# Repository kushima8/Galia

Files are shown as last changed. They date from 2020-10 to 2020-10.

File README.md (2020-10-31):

# Galia
Split 61-key ergo keyboard with trackball on right-hand side.

## Disclaimer
The layout is based on the [Ergodash](https://github.com/omkbd/ErgoDash) layout with the inner-most keys removed and a modified thumb cluster on the left hand side, and integrated 34mm trackball on the right. The Pro Micro position was also moved inwards to allow for a thinner board. The Ergodash layout was only used as a reference, nothing was copied and the board is a completely new design. Finally, the mechanical design of the [aball](https://github.com/brickbots/aball) was referenced for the design of the trackball mount, but an entirely new design was created.

## Key Features
* Slim design, or as slim as I could get while using standard MX-style Switches. Essentially, the Pro Micro or whatever other microcontroller used mounts under the PCB, flush and facing up with the help of a cutout.
* SMK MX-style switch support, solder only but the holes are mill-max socket compatible.
* OLED support, either using a standard 0.91" SSD1306 OLED or the [Crenshaw](https://github.com/Ariamelon/Crenshaw) 1.3" OLED breakout board.
* Single rotary encoder position replacing the top-most switch of the left thumb cluster.
* 34mm trackball on the right-hand side using the [Ogen](https://github.com/Ariamelon/Ogen) PMW3360 sensor board. Also compatible with [Jack's](https://www.tindie.com/products/jkicklighter/pmw3360-motion-sensor/) version. 
* Useable in both wired and wireless modes.
* Supports either charger on the microcontroller board or an external TP4056-based charger for faster charging. the TP4056 charger is also flush-mounted sitting up and supports the use of 0305 or 7305 mill-max hotswap sockets if desired.
* Case design with plate included with in-built 10° tent. Plate assumes use of the Crenshaw.
* Supports a massive battery due to the large space in the case. I'm personally using 18650 batteries. Go a year without charging!

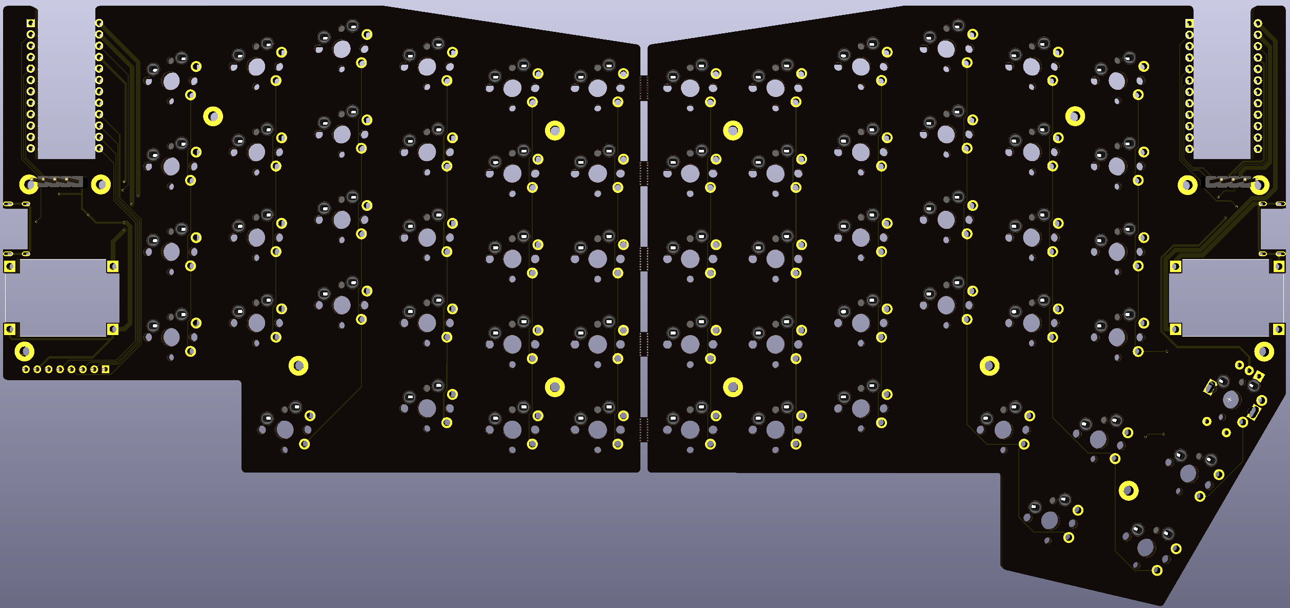
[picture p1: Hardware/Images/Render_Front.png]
Galia Front Render

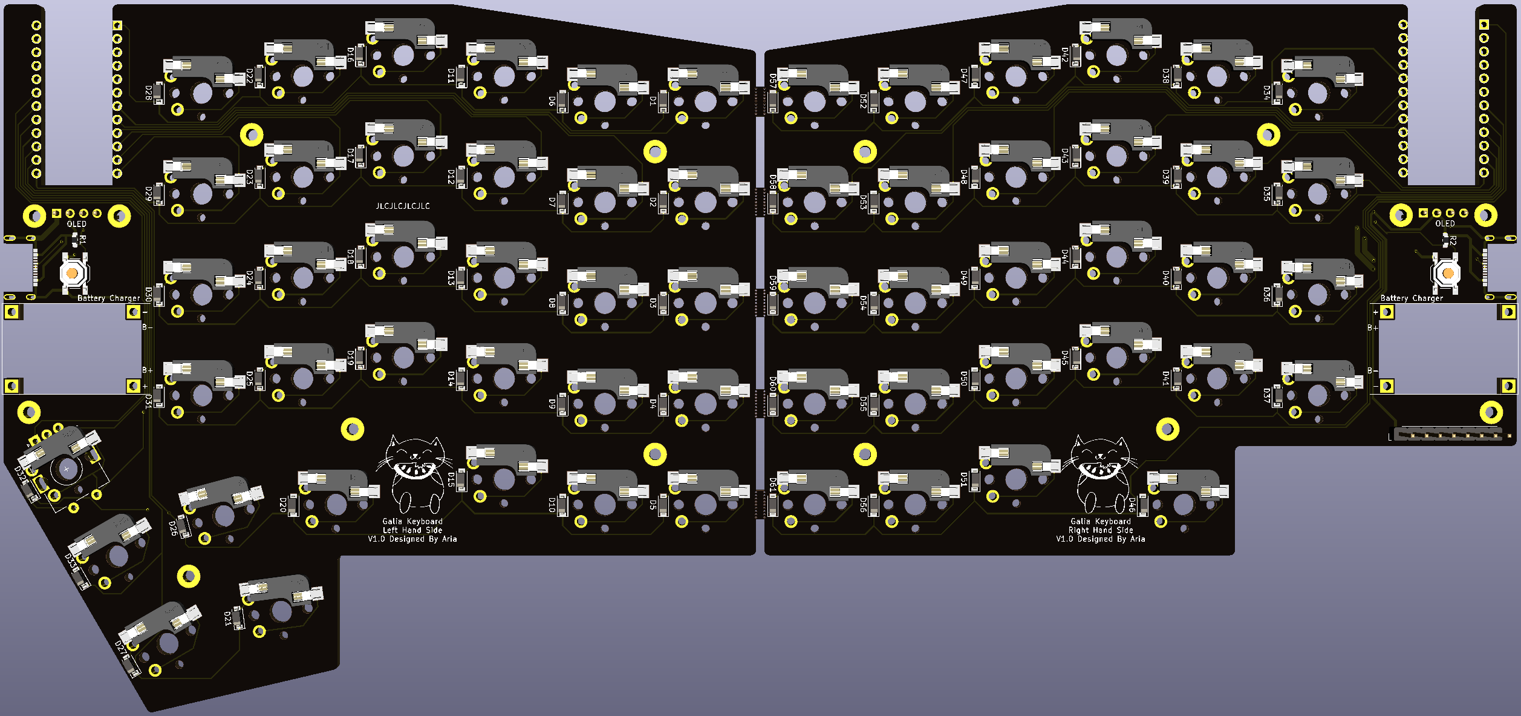
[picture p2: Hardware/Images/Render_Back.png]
Galia Back Render


## Changelog
* 02/10/2020: Initial commit with case.
* 06/10/2020: Added spot for external TP4056 charger board.
* 10/10/2020: Changed reset switch footprint and position, removed useless pull-up resistor.
* 11/10/2020: Now uses much less plastic and the position of the trackball was moved inwards and downwards.

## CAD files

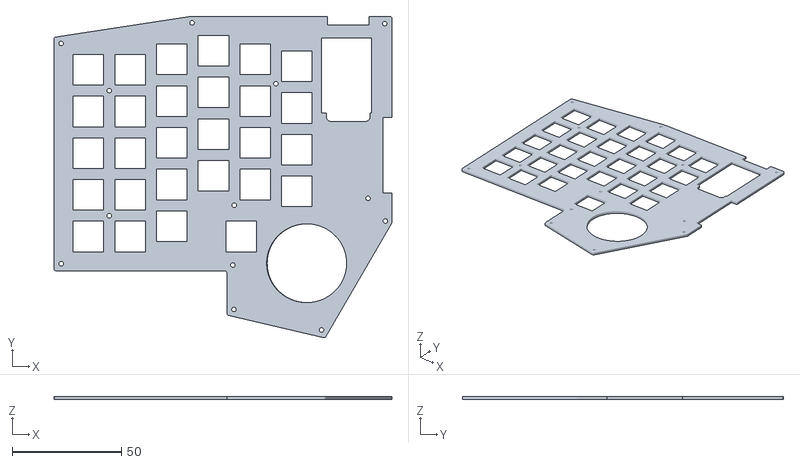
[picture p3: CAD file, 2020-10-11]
Hardware/Case/Plate_R.stl
154.5 x 146.9 x 1.50

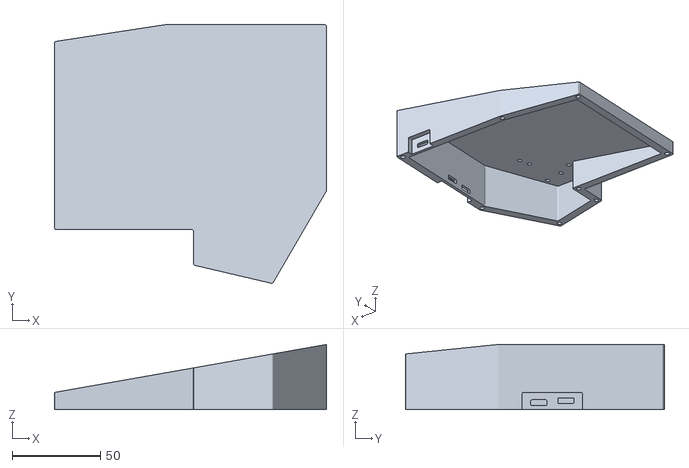
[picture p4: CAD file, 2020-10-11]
Hardware/Case/Case_R.stl
154.5 x 146.9 x 37.0

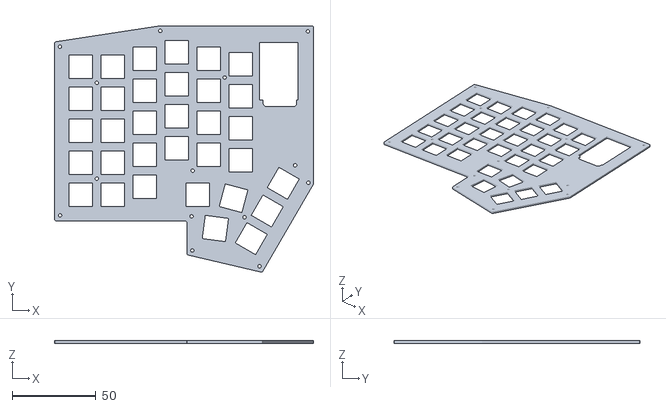
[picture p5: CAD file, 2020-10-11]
Hardware/Case/Plate_L.stl
154.5 x 146.9 x 1.50

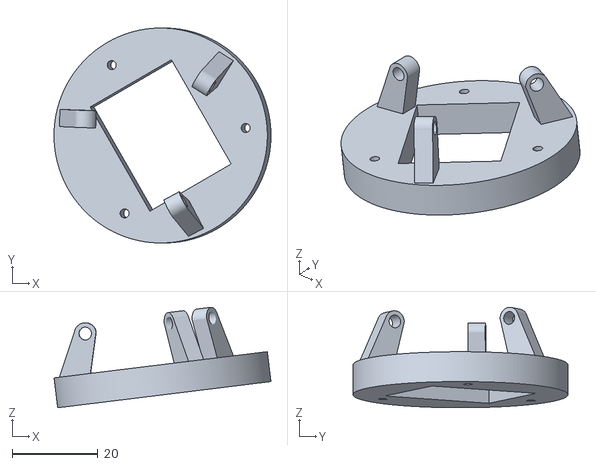
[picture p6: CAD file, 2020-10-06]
Hardware/Case/Trackball_Base.stl
50.5 x 50.0 x 23.4

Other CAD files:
Hardware/Case/Case_L.stl
Hardware/Case/Plate_L.dxf
Hardware/Case/Plate_R.dxf

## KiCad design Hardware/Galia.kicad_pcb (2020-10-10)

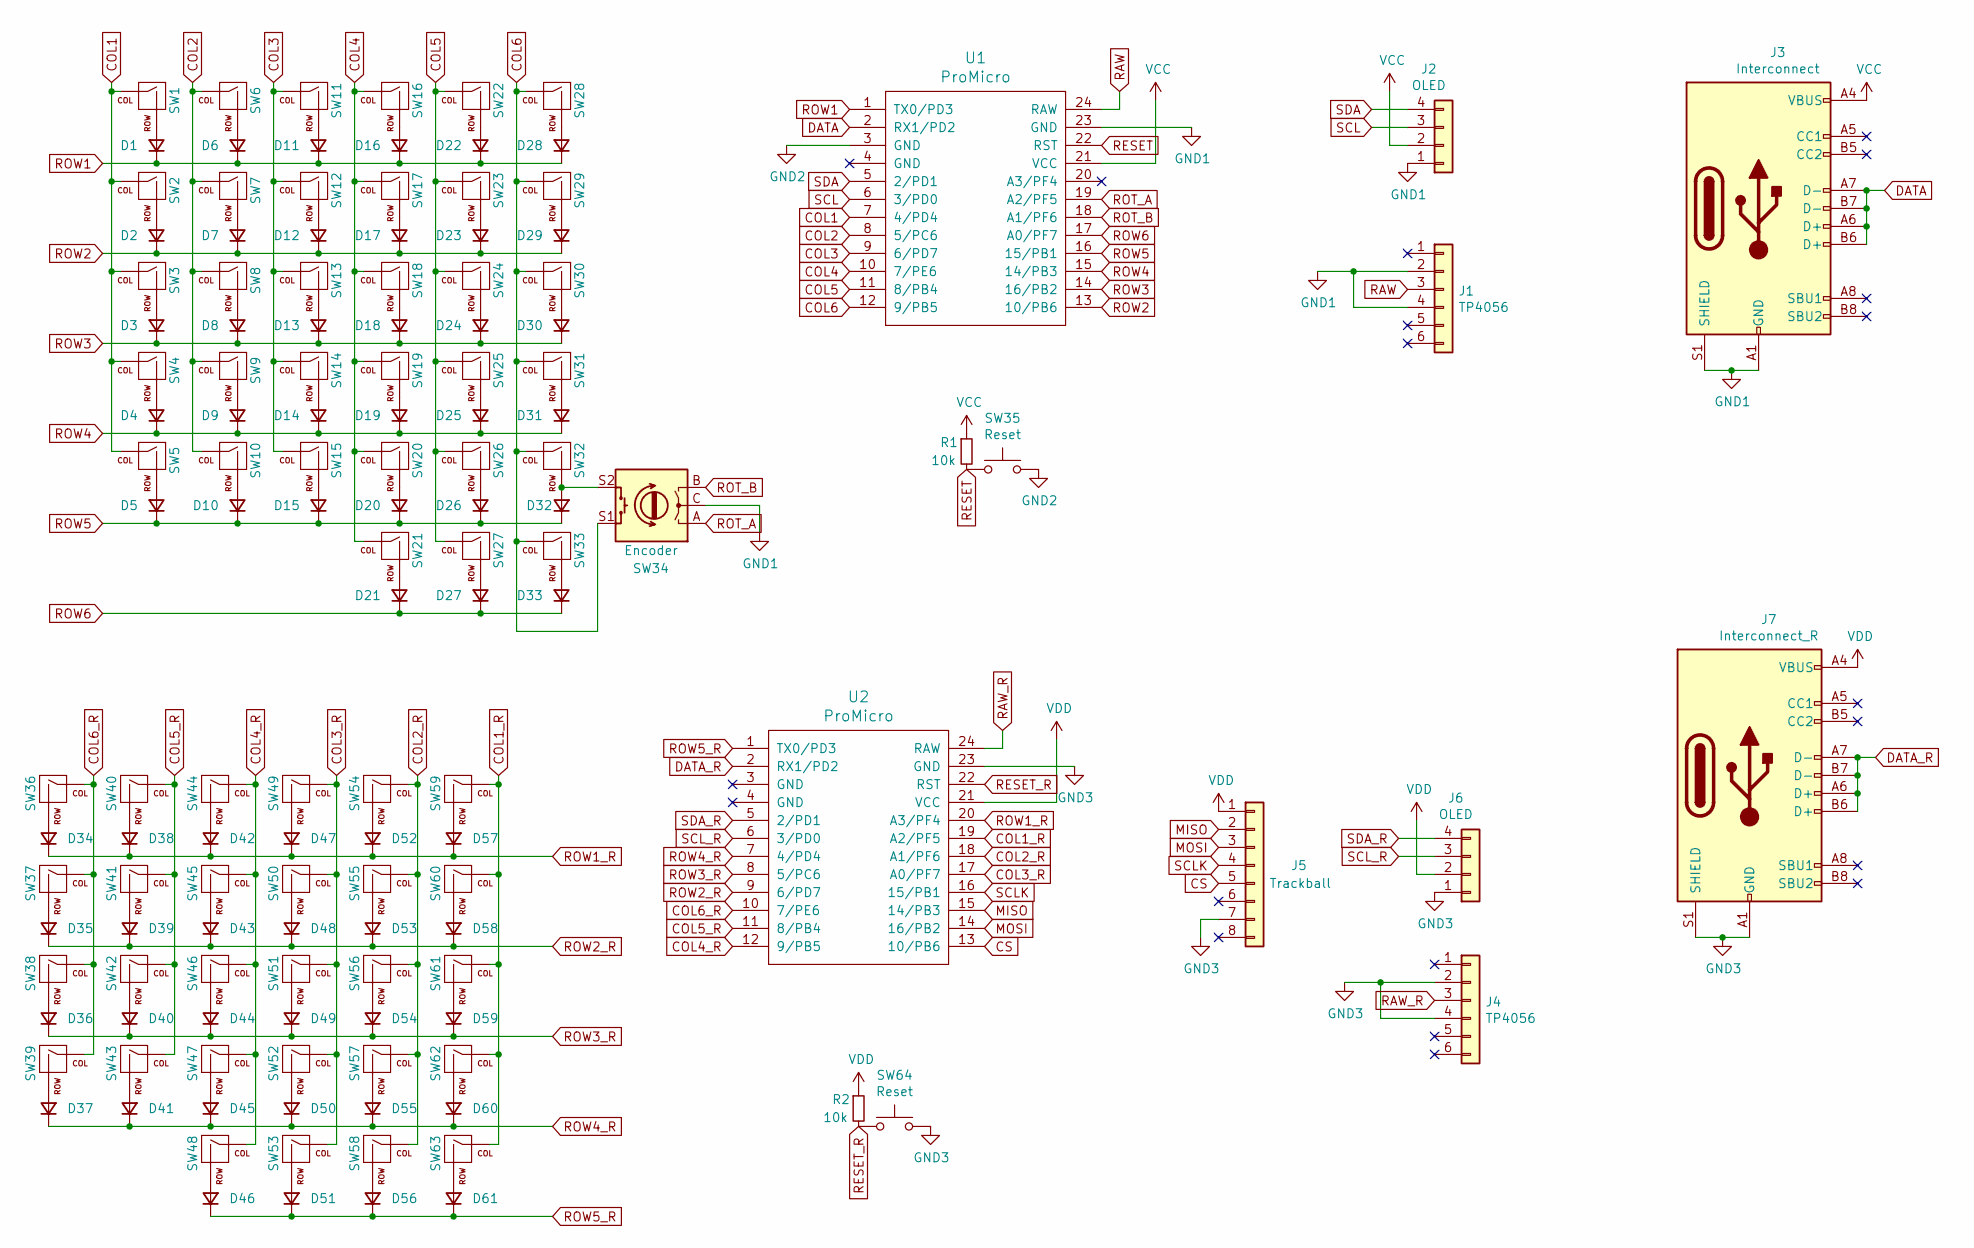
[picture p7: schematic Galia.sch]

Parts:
D1, D2, D3, D4, D5, D6, D7, D8, D9, D10, D11, D12, D13, D14, D15, D16, D17, D18, D19, D20, D21, D22, D23, D24, D25, D26, D27, D28, D29, D30, D31, D32, D33, D34, D35, D36, D37, D38, D39, D40, D41, D42, D43, D44, D45, D46, D47, D48, D49, D50, D51, D52, D53, D54, D55, D56, D57, D58, D59, D60, D61: D; D_SOD-123
J1, J4: TP4056; TP4056-18650
J2, J6: OLED; PinHeader_1x04_P2.54mm_Vertical_No_Silk
J3: Interconnect; USB-C-C168688
J5: Trackball; PinHeader_1x08_P2.54mm_Vertical
J7: Interconnect_R; USB-C-C168688
R1, R2: 10k; R_0603_1608Metric_Pad1.05x0.95mm_HandSolder
SW1, SW2, SW3, SW4, SW5, SW6, SW7, SW8, SW9, SW10, SW11, SW12, SW13, SW14, SW15, SW16, SW17, SW18, SW19, SW20, SW21, SW22, SW23, SW24, SW25, SW26, SW27, SW28, SW29, SW30, SW31, SW32, SW33, SW36, SW37, SW38, SW39, SW40, SW41, SW42, SW43, SW44, SW45, SW46, SW47, SW48, SW49, SW50, SW51, SW52, SW53, SW54, SW55, SW56, SW57, SW58, SW59, SW60, SW61, SW62, SW63: MX; CherryMX_Hotswap_SMK
SW34: Encoder; RotaryEncoder_Alps_EC11E-Switch_Vertical_H20mm
SW35, SW64: Reset; Switch_Tactile_SPST_Angled_MJTP1117
U1, U2: ProMicro; ArduinoProMicro_Blank

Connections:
COL1: SW1.1 (COL), SW2.1 (COL), SW3.1 (COL), SW4.1 (COL), SW5.1 (COL), U1.7 (4/PD4)
COL1_R: SW59.1 (COL), SW60.1 (COL), SW61.1 (COL), SW62.1 (COL), SW63.1 (COL), U2.19 (A2/PF5)
COL2: SW6.1 (COL), SW7.1 (COL), SW8.1 (COL), SW9.1 (COL), SW10.1 (COL), U1.8 (5/PC6)
COL2_R: SW54.1 (COL), SW55.1 (COL), SW56.1 (COL), SW57.1 (COL), SW58.1 (COL), U2.18 (A1/PF6)
COL3: SW11.1 (COL), SW12.1 (COL), SW13.1 (COL), SW14.1 (COL), SW15.1 (COL), U1.9 (6/PD7)
COL3_R: SW49.1 (COL), SW50.1 (COL), SW51.1 (COL), SW52.1 (COL), SW53.1 (COL), U2.17 (A0/PF7)
COL4: SW16.1 (COL), SW17.1 (COL), SW18.1 (COL), SW19.1 (COL), SW20.1 (COL), SW21.1 (COL), U1.10 (7/PE6)
COL4_R: SW44.1 (COL), SW45.1 (COL), SW46.1 (COL), SW47.1 (COL), SW48.1 (COL), U2.12 (9/PB5)
COL5: SW22.1 (COL), SW23.1 (COL), SW24.1 (COL), SW25.1 (COL), SW26.1 (COL), SW27.1 (COL), U1.11 (8/PB4)
COL5_R: SW40.1 (COL), SW41.1 (COL), SW42.1 (COL), SW43.1 (COL), U2.11 (8/PB4)
COL6: SW28.1 (COL), SW29.1 (COL), SW30.1 (COL), SW31.1 (COL), SW32.1 (COL), SW33.1 (COL), SW34.S1, U1.12 (9/PB5)
COL6_R: SW36.1 (COL), SW37.1 (COL), SW38.1 (COL), SW39.1 (COL), U2.10 (7/PE6)
CS: J5.5, U2.13 (10/PB6)
DATA: J3.A6 (D+), J3.A7 (D-), J3.B6 (D+), J3.B7 (D-), U1.2 (RX1/PD2)
DATA_R: J7.A6 (D+), J7.A7 (D-), J7.B6 (D+), J7.B7 (D-), U2.2 (RX1/PD2)
GND1: J1.2, J1.4, J2.1, J3.A1 (GND), J3.A12 (GND), J3.B1 (GND), J3.B12 (GND), J3.S1 (SHIELD), SW34.C, U1.23 (GND)
GND2: SW35.2, U1.3 (GND)
GND3: J4.2, J4.4, J5.7, J6.1, J7.A1 (GND), J7.A12 (GND), J7.B1 (GND), J7.B12 (GND), J7.S1 (SHIELD), SW64.2, U2.23 (GND)
MISO: J5.2, U2.15 (14/PB3)
MOSI: J5.3, U2.14 (16/PB2)
unnamed: D1.2 (A), SW1.2 (ROW)
unnamed: D2.2 (A), SW2.2 (ROW)
unnamed: D3.2 (A), SW3.2 (ROW)
unnamed: D4.2 (A), SW4.2 (ROW)
unnamed: D5.2 (A), SW5.2 (ROW)
unnamed: D6.2 (A), SW6.2 (ROW)
unnamed: D7.2 (A), SW7.2 (ROW)
unnamed: D8.2 (A), SW8.2 (ROW)
unnamed: D9.2 (A), SW9.2 (ROW)
unnamed: D10.2 (A), SW10.2 (ROW)
unnamed: D11.2 (A), SW11.2 (ROW)
unnamed: D12.2 (A), SW12.2 (ROW)
unnamed: D13.2 (A), SW13.2 (ROW)
unnamed: D14.2 (A), SW14.2 (ROW)
unnamed: D15.2 (A), SW15.2 (ROW)
unnamed: D16.2 (A), SW16.2 (ROW)
unnamed: D17.2 (A), SW17.2 (ROW)
unnamed: D18.2 (A), SW18.2 (ROW)
unnamed: D19.2 (A), SW19.2 (ROW)
unnamed: D20.2 (A), SW20.2 (ROW)
unnamed: D21.2 (A), SW21.2 (ROW)
unnamed: D22.2 (A), SW22.2 (ROW)
unnamed: D23.2 (A), SW23.2 (ROW)
unnamed: D24.2 (A), SW24.2 (ROW)
unnamed: D25.2 (A), SW25.2 (ROW)
unnamed: D26.2 (A), SW26.2 (ROW)
unnamed: D27.2 (A), SW27.2 (ROW)
unnamed: D28.2 (A), SW28.2 (ROW)
unnamed: D29.2 (A), SW29.2 (ROW)
unnamed: D30.2 (A), SW30.2 (ROW)
unnamed: D31.2 (A), SW31.2 (ROW)
unnamed: D32.2 (A), SW32.2 (ROW), SW34.S2
unnamed: D33.2 (A), SW33.2 (ROW)
unnamed: D34.2 (A), SW36.2 (ROW)
unnamed: D35.2 (A), SW37.2 (ROW)
unnamed: D36.2 (A), SW38.2 (ROW)
unnamed: D37.2 (A), SW39.2 (ROW)
unnamed: D38.2 (A), SW40.2 (ROW)
unnamed: D39.2 (A), SW41.2 (ROW)
unnamed: D40.2 (A), SW42.2 (ROW)
unnamed: D41.2 (A), SW43.2 (ROW)
unnamed: D42.2 (A), SW44.2 (ROW)
unnamed: D43.2 (A), SW45.2 (ROW)
unnamed: D44.2 (A), SW46.2 (ROW)
unnamed: D45.2 (A), SW47.2 (ROW)
unnamed: D46.2 (A), SW48.2 (ROW)
unnamed: D47.2 (A), SW49.2 (ROW)
unnamed: D48.2 (A), SW50.2 (ROW)
unnamed: D49.2 (A), SW51.2 (ROW)
unnamed: D50.2 (A), SW52.2 (ROW)
unnamed: D51.2 (A), SW53.2 (ROW)
unnamed: D52.2 (A), SW54.2 (ROW)
unnamed: D53.2 (A), SW55.2 (ROW)
unnamed: D54.2 (A), SW56.2 (ROW)
unnamed: D55.2 (A), SW57.2 (ROW)
unnamed: D56.2 (A), SW58.2 (ROW)
unnamed: D57.2 (A), SW59.2 (ROW)
unnamed: D58.2 (A), SW60.2 (ROW)
unnamed: D59.2 (A), SW61.2 (ROW)
unnamed: D60.2 (A), SW62.2 (ROW)
unnamed: D61.2 (A), SW63.2 (ROW)
RAW: J1.3, U1.24 (RAW)
RAW_R: J4.3, U2.24 (RAW)
RESET: R1.2, SW35.1, U1.22 (RST)
RESET_R: R2.2, SW64.1, U2.22 (RST)
ROT_A: SW34.A, U1.19 (A2/PF5)
ROT_B: SW34.B, U1.18 (A1/PF6)
ROW1: D1.1 (K), D6.1 (K), D11.1 (K), D16.1 (K), D22.1 (K), D28.1 (K), U1.1 (TX0/PD3)
ROW1_R: D34.1 (K), D38.1 (K), D42.1 (K), D47.1 (K), D52.1 (K), D57.1 (K), U2.20 (A3/PF4)
ROW2: D2.1 (K), D7.1 (K), D12.1 (K), D17.1 (K), D23.1 (K), D29.1 (K), U1.13 (10/PB6)
ROW2_R: D35.1 (K), D39.1 (K), D43.1 (K), D48.1 (K), D53.1 (K), D58.1 (K), U2.9 (6/PD7)
ROW3: D3.1 (K), D8.1 (K), D13.1 (K), D18.1 (K), D24.1 (K), D30.1 (K), U1.14 (16/PB2)
ROW3_R: D36.1 (K), D40.1 (K), D44.1 (K), D49.1 (K), D54.1 (K), D59.1 (K), U2.8 (5/PC6)
ROW4: D4.1 (K), D9.1 (K), D14.1 (K), D19.1 (K), D25.1 (K), D31.1 (K), U1.15 (14/PB3)
ROW4_R: D37.1 (K), D41.1 (K), D45.1 (K), D50.1 (K), D55.1 (K), D60.1 (K), U2.7 (4/PD4)
ROW5: D5.1 (K), D10.1 (K), D15.1 (K), D20.1 (K), D26.1 (K), D32.1 (K), U1.16 (15/PB1)
ROW5_R: D46.1 (K), D51.1 (K), D56.1 (K), D61.1 (K), U2.1 (TX0/PD3)
ROW6: D21.1 (K), D27.1 (K), D33.1 (K), U1.17 (A0/PF7)
SCL: J2.3, U1.6 (3/PD0)
SCLK: J5.4, U2.16 (15/PB1)
SCL_R: J6.3, U2.6 (3/PD0)
SDA: J2.4, U1.5 (2/PD1)
SDA_R: J6.4, U2.5 (2/PD1)
VCC: J2.2, J3.A4 (VBUS), J3.A9 (VBUS), J3.B4 (VBUS), J3.B9 (VBUS), R1.1, U1.21 (VCC)
VDD: J5.1, J6.2, J7.A4 (VBUS), J7.A9 (VBUS), J7.B4 (VBUS), J7.B9 (VBUS), R2.1, U2.21 (VCC)

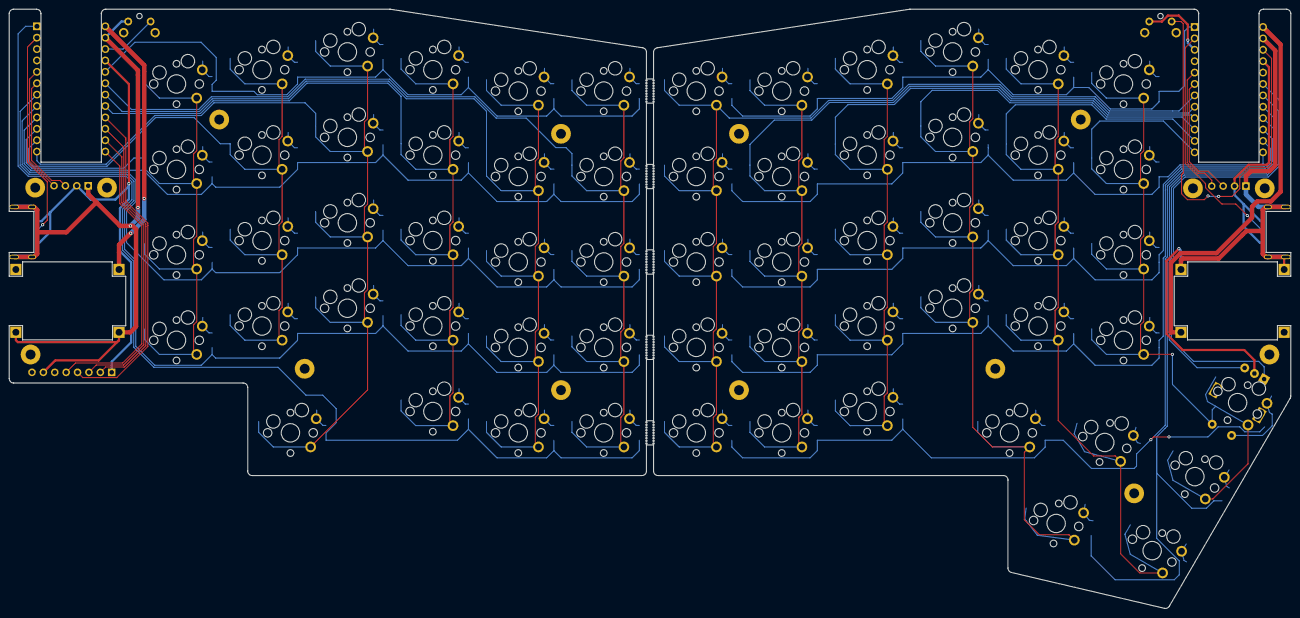
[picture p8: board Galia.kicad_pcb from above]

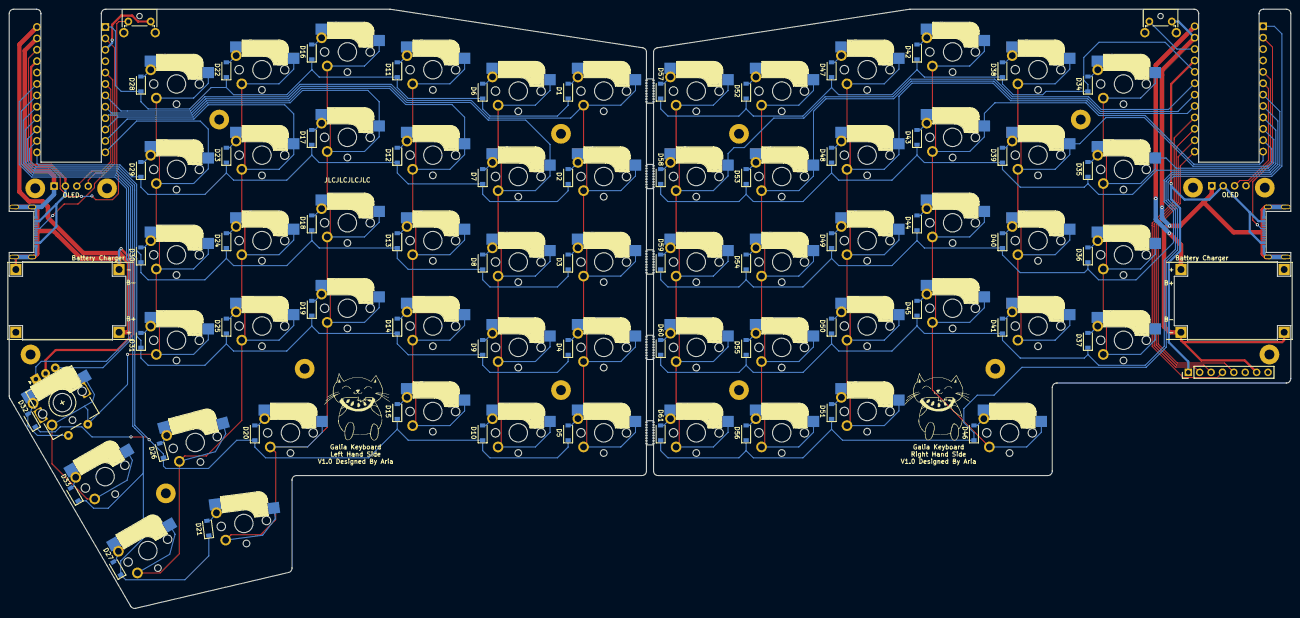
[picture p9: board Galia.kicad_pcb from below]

Board: 2 copper layers, 285.7 x 133.6 mm, 136 parts (68 on the bottom side), 105 nets.

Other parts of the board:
G1, G2: Art; Catmelon

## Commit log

2020-10-04 Updated silkscreen
    [Galia-B_Cu.gbr, Galia-B_Mask.gbr, Galia-B_Paste.gbr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]
2020-10-05 Added spot for TP4056 charger
    [Galia-B_Adhes.dxf, Galia-B_CrtYd.dxf, Galia-B_Cu.dxf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]
2020-10-06 Updated readme and added renders
    [Galia-B_Adhes.dxf, Galia-B_CrtYd.dxf, Galia-B_Cu.dxf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]
2020-10-06 Changed readme and added license
    [Plate_L.dxf, Plate_R.dxf]
2020-10-10 Changed reset switch footprint and position, removed pull-up resistor
    [Galia.kicad_pcb, Galia.sch]
2020-10-11 Big update to case
    Now uses much less plastic and the position of the trackball was moved inwards and downwards
    [Case_L.stl, Case_R.stl, Plate_L.stl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]
